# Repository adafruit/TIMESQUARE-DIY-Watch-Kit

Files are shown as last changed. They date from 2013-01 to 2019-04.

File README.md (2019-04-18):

# PCB for the Adafruit TIMESQUARE DIY Watch Kit 

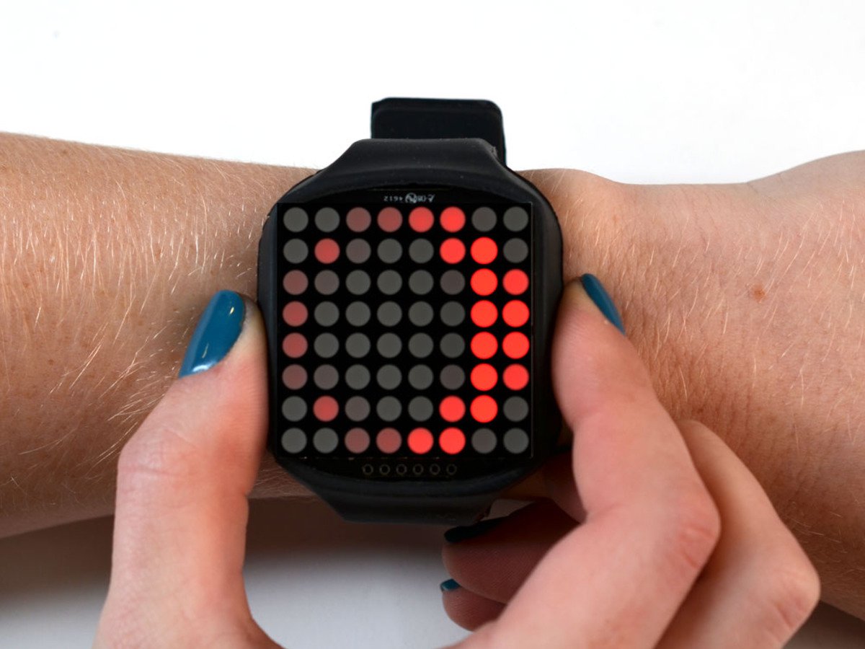
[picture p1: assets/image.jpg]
<a href="http://www.adafruit.com/products/1106"><br/>Click here to purchase one from the Adafruit shop</a>

__Format is EagleCAD schematic and board layout__

Show up stylish AND on time to any event with this awesome looking DIY watch. We have a few watch kits here at Adafruit but we finally have one that looks good and fits well, even for ladies and kids and others with smaller wrists and hands. Its got an 8x8 bit matrix display and a repurposed silicone watch band for a professional look.

64 LEDs light up to tell you the time in a variety of ways. Built into the kit are 3 different watch 'faces' - a scrolling marquee with time and date, a binary watch display (for geeks, robots, and binary fans), and a moon phase display (for beach-combers, werewolves). There's also a built-in battery meter so you can check your battery life. [Want to make your own watch? Easy! The microcontroller is an Arduino-compatible, all you need is an FTDI Friend and the Arduino IDE and you can design your own watch faces and upload them to the TIMESQUARE.](http://learn.adafruit.com/timesquare-watch-kit/uploading-new-firmware)

Engineered for greatness by PaintYourDragon, this watch squeezes 500-1000 full time displays out of a coin battery, and up to one year 'resting' lifetime, so you can use this as a day-to-day timekeeper.

This watch comes with an ultra bright red LED matrix and a black silicone watch band that fits all wrists from children to adult.

The band is an "off-the-shelf" band that holds the watch in pretty well, we'll be creating other bands - the included band is to just get you started! This watch is meant to be hackable, from the software to the band!

This is a DIY kit, and requires some basic soldering/assembly to put together. It is a beginner kit, so this is a fine project to use in learning how to solder. Tools are not included, you'll need a soldering iron, solder and diagonal cutters as a minimum. [Check the tutorial page for details on what tools and steps are required to assemble.](http://learn.adafruit.com/timesquare-watch-kit). Take about 1-2 hours to put together. Build it in the afternoon and you'll be done in time to hit the clubs in the evening.

[For more information and downloads check out the page in the Adafruit Learning System.](http://learn.adafruit.com/timesquare-watch-kit)

## License
Adafruit invests time and resources providing this open source design,
please support Adafruit and open-source hardware by purchasing
products from Adafruit!

Designed by Adafruit Industries.
Creative Commons Attribution, Share-Alike license, check license.txt for more information
All text above must be included in any redistribution

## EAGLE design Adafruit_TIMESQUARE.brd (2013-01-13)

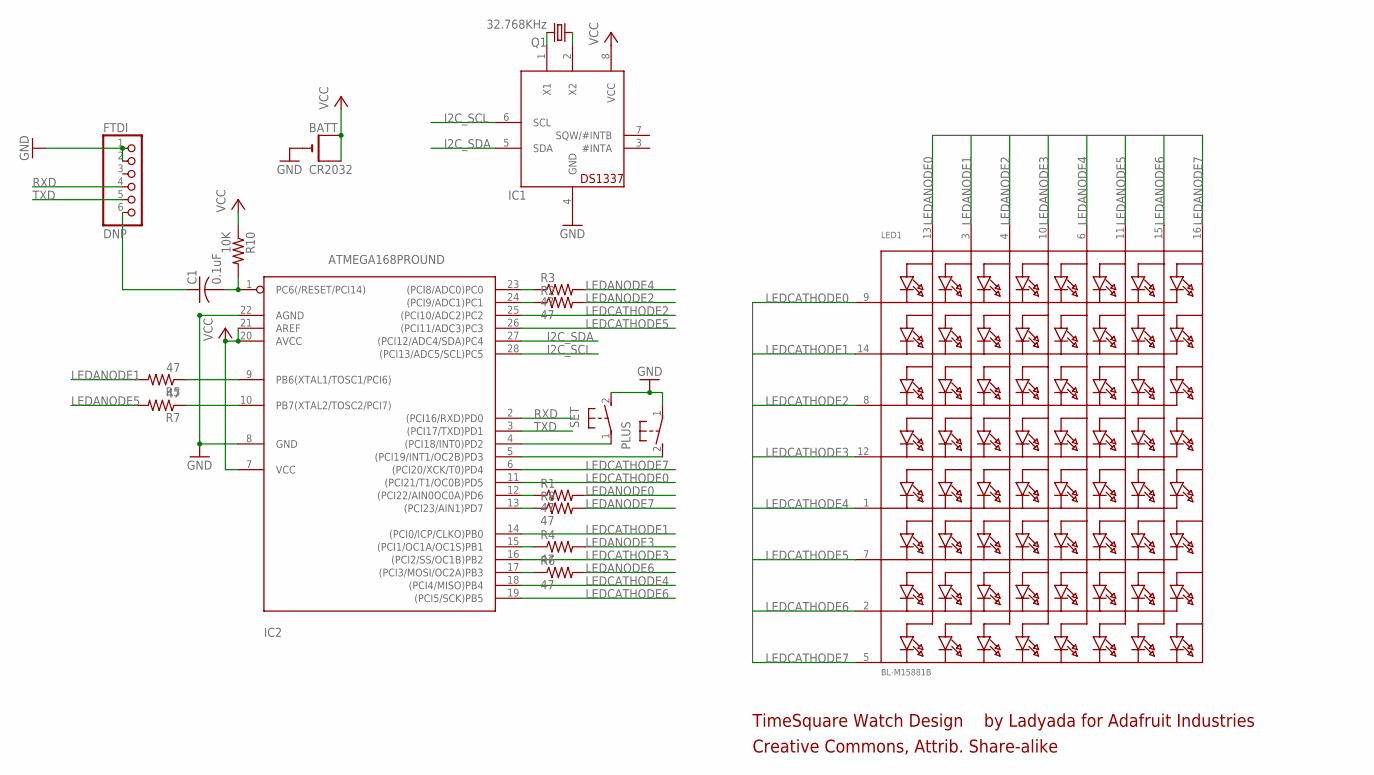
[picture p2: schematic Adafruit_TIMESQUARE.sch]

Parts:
BATT: CR2032; CR2032-THRU
C1: 0.1uF; C025-025X050
FTDI: DNP; 1X06-CLEAN
IC1: DS1337; DIL08-ROUND
IC2: ATMEGA168PROUND; DIL28-3-ROUND
LED1: BL-M15881B; SEGMENT_BL-M15A881
PLUS: 31-XXSKINNY; B3F-31XX-SKINNIER
Q1: 32.768KHz; TC38H
R1, R2, R3, R4, R5, R6, R7, R8: 47; 0204/7
R10: 10K; 0204/7
SET: 31-XXSKINNY; B3F-31XX-SKINNIER

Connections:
GND: BATT.-, FTDI.1, FTDI.2, IC1.4 (GND), IC2.8 (GND), IC2.22 (AGND), PLUS.1, SET.2 (S)
I2C_SCL: IC1.6 (SCL), IC2.28 ((PCI13/ADC5/SCL)PC5)
I2C_SDA: IC1.5 (SDA), IC2.27 ((PCI12/ADC4/SDA)PC4)
LEDANODE0: LED1.13 (A1), R1.2
LEDANODE1: LED1.3 (A2), R5.2
LEDANODE2: LED1.4 (A3), R2.2
LEDANODE3: LED1.10 (A4), R4.2
LEDANODE4: LED1.6 (A5), R3.2
LEDANODE5: LED1.11 (A6), R7.2
LEDANODE6: LED1.15 (A7), R6.2
LEDANODE7: LED1.16 (A8), R8.2
LEDCATHODE0: IC2.11 ((PCI21/T1/OC0B)PD5), LED1.9 (K1)
LEDCATHODE1: IC2.14 ((PCI0/ICP/CLKO)PB0), LED1.14 (K2)
LEDCATHODE2: IC2.25 ((PCI10/ADC2)PC2), LED1.8 (K3)
LEDCATHODE3: IC2.16 ((PCI2/SS/OC1B)PB2), LED1.12 (K4)
LEDCATHODE4: IC2.18 ((PCI4/MISO)PB4), LED1.1 (K5)
LEDCATHODE5: IC2.26 ((PCI11/ADC3)PC3), LED1.7 (K6)
LEDCATHODE6: IC2.19 ((PCI5/SCK)PB5), LED1.2 (K7)
LEDCATHODE7: IC2.6 ((PCI20/XCK/T0)PD4), LED1.5 (K8)
unnamed: C1.2, IC2.1 (PC6(/RESET/PCI14)), R10.2
unnamed: IC1.1 (X1), Q1.2
unnamed: IC1.2 (X2), Q1.1
unnamed: IC2.4 ((PCI18/INT0)PD2), SET.1
unnamed: IC2.5 ((PCI19/INT1/OC2B)PD3), PLUS.2 (S)
unnamed: IC2.12 ((PCI22/AIN0OC0A)PD6), R1.1
unnamed: IC2.23 ((PCI8/ADC0)PC0), R3.1
unnamed: IC2.9 (PB6(XTAL1/TOSC1/PCI6)), R5.1
unnamed: IC2.10 (PB7(XTAL2/TOSC2/PCI7)), R7.1
unnamed: IC2.24 ((PCI9/ADC1)PC1), R2.1
unnamed: IC2.17 ((PCI3/MOSI/OC2A)PB3), R6.1
unnamed: IC2.13 ((PCI23/AIN1)PD7), R8.1
unnamed: IC2.15 ((PCI1/OC1A/OC1S)PB1), R4.1
unnamed: C1.1, FTDI.6
RXD: FTDI.4, IC2.2 ((PCI16/RXD)PD0)
TXD: FTDI.5, IC2.3 ((PCI17/TXD)PD1)
VCC: BATT.+1 (+), BATT.+2 (+1), IC1.8 (VCC), IC2.7 (VCC), IC2.20 (AVCC), IC2.21 (AREF), R10.1

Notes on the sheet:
TimeSquare Watch Design
by Ladyada for Adafruit Industries
Creative Commons, Attrib. Share-alike

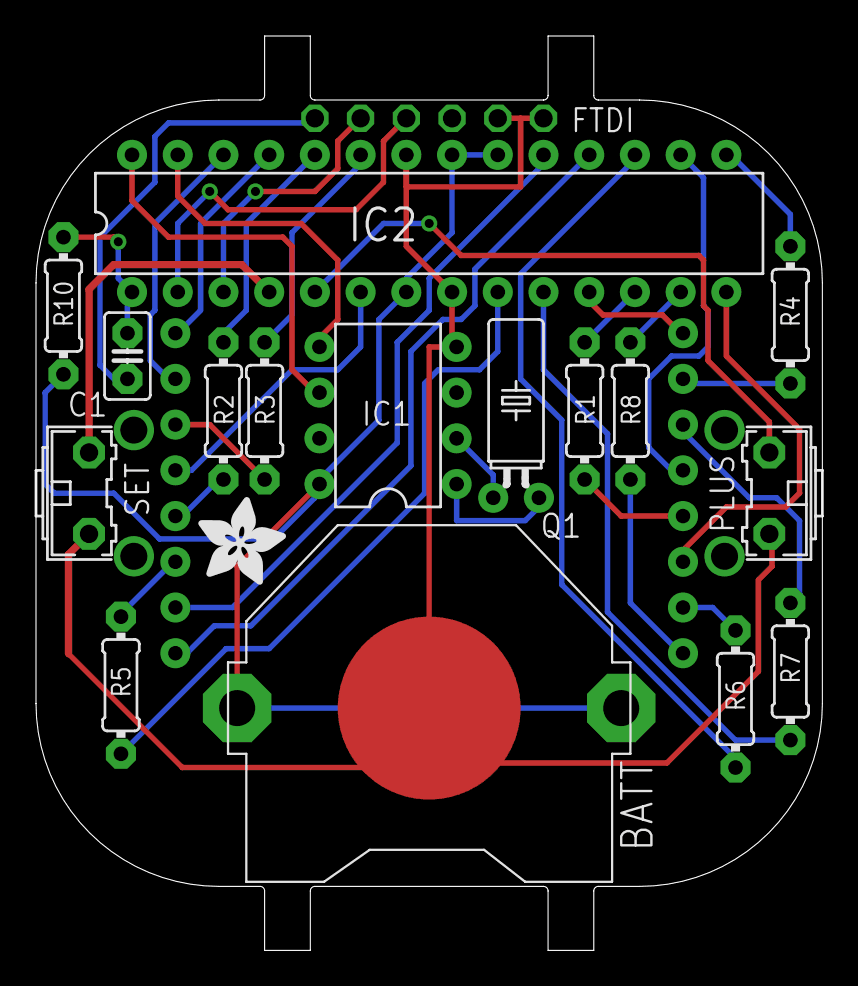
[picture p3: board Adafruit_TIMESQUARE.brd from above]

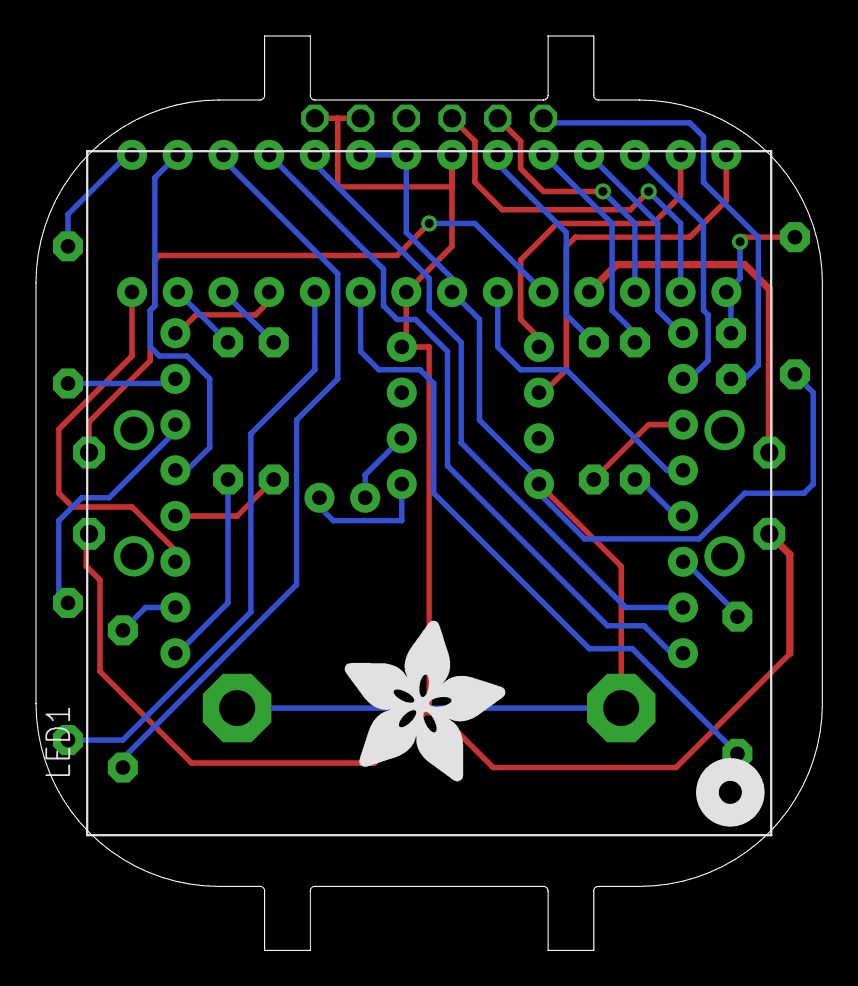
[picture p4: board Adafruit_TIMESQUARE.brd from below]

Board: 2 copper layers, 43.7 x 50.8 mm, 20 parts (2 on the bottom side), 36 nets.

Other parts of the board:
U$1: ADAFRUIT_5MM
U$2: ADAFRUIT_9MM

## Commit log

2013-01-13 Eagle files!
    [TIMESQUARE.brd, TIMESQUARE.sch]
2013-01-13 read me
    [Adafruit_TIMESQUARE.brd, Adafruit_TIMESQUARE.sch]

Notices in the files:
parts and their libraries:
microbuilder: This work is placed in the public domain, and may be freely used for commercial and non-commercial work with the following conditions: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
